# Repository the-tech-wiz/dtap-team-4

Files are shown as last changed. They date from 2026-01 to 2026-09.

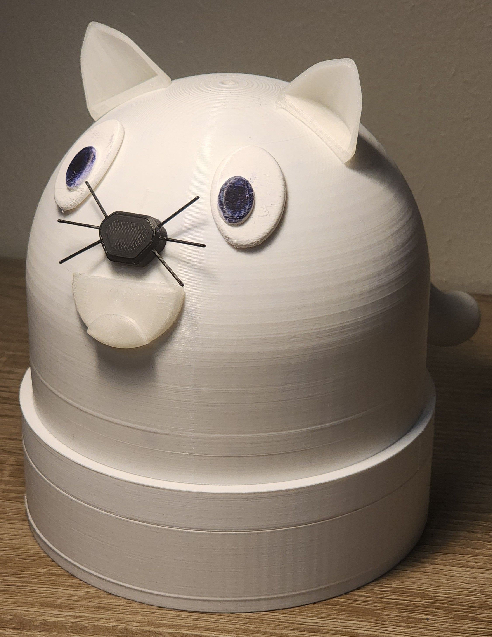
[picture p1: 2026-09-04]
image.jpg

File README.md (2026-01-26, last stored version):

# DTAP Team 4

## Getting started

To make it easy for you to get started with GitLab, here's a list of recommended next steps.

Already a pro? Just edit this README.md and make it your own. Want to make it easy? [Use the template at the bottom](#editing-this-readme)!

## Add your files

- [ ] [Create](https://docs.gitlab.com/ee/user/project/repository/web_editor.html#create-a-file) or [upload](https://docs.gitlab.com/ee/user/project/repository/web_editor.html#upload-a-file) files
- [ ] [Add files using the command line](https://docs.gitlab.com/topics/git/add_files/#add-files-to-a-git-repository) or push an existing Git repository with the following command:

```
cd existing_repo
git remote add origin https://version.aalto.fi/gitlab/lel4/dtap-team-4.git
git branch -M main
git push -uf origin main
```

## Integrate with your tools

- [ ] [Set up project integrations](https://version.aalto.fi/gitlab/lel4/dtap-team-4/-/settings/integrations)

## Collaborate with your team

- [ ] [Invite team members and collaborators](https://docs.gitlab.com/ee/user/project/members/)
- [ ] [Create a new merge request](https://docs.gitlab.com/ee/user/project/merge_requests/creating_merge_requests.html)
- [ ] [Automatically close issues from merge requests](https://docs.gitlab.com/ee/user/project/issues/managing_issues.html#closing-issues-automatically)
- [ ] [Enable merge request approvals](https://docs.gitlab.com/ee/user/project/merge_requests/approvals/)
- [ ] [Set auto-merge](https://docs.gitlab.com/user/project/merge_requests/auto_merge/)

## Test and Deploy

Use the built-in continuous integration in GitLab.

- [ ] [Get started with GitLab CI/CD](https://docs.gitlab.com/ee/ci/quick_start/)
- [ ] [Analyze your code for known vulnerabilities with Static Application Security Testing (SAST)](https://docs.gitlab.com/ee/user/application_security/sast/)
- [ ] [Deploy to Kubernetes, Amazon EC2, or Amazon ECS using Auto Deploy](https://docs.gitlab.com/ee/topics/autodevops/requirements.html)
- [ ] [Use pull-based deployments for improved Kubernetes management](https://docs.gitlab.com/ee/user/clusters/agent/)
- [ ] [Set up protected environments](https://docs.gitlab.com/ee/ci/environments/protected_environments.html)

***

# Editing this README

When you're ready to make this README your own, just edit this file and use the handy template below (or feel free to structure it however you want - this is just a starting point!). Thanks to [makeareadme.com](https://www.makeareadme.com/) for this template.

## Suggestions for a good README

Every project is different, so consider which of these sections apply to yours. The sections used in the template are suggestions for most open source projects. Also keep in mind that while a README can be too long and detailed, too long is better than too short. If you think your README is too long, consider utilizing another form of documentation rather than cutting out information.

## Name
Choose a self-explaining name for your project.

## Description
Let people know what your project can do specifically. Provide context and add a link to any reference visitors might be unfamiliar with. A list of Features or a Background subsection can also be added here. If there are alternatives to your project, this is a good place to list differentiating factors.

## Badges
On some READMEs, you may see small images that convey metadata, such as whether or not all the tests are passing for the project. You can use Shields to add some to your README. Many services also have instructions for adding a badge.

## Visuals
Depending on what you are making, it can be a good idea to include screenshots or even a video (you'll frequently see GIFs rather than actual videos). Tools like ttygif can help, but check out Asciinema for a more sophisticated method.

## Installation
Within a particular ecosystem, there may be a common way of installing things, such as using Yarn, NuGet, or Homebrew. However, consider the possibility that whoever is reading your README is a novice and would like more guidance. Listing specific steps helps remove ambiguity and gets people to using your project as quickly as possible. If it only runs in a specific context like a particular programming language version or operating system or has dependencies that have to be installed manually, also add a Requirements subsection.

## Usage
Use examples liberally, and show the expected output if you can. It's helpful to have inline the smallest example of usage that you can demonstrate, while providing links to more sophisticated examples if they are too long to reasonably include in the README.

## Support
Tell people where they can go to for help. It can be any combination of an issue tracker, a chat room, an email address, etc.

## Roadmap
If you have ideas for releases in the future, it is a good idea to list them in the README.

## Contributing
State if you are open to contributions and what your requirements are for accepting them.

For people who want to make changes to your project, it's helpful to have some documentation on how to get started. Perhaps there is a script that they should run or some environment variables that they need to set. Make these steps explicit. These instructions could also be useful to your future self.

You can also document commands to lint the code or run tests. These steps help to ensure high code quality and reduce the likelihood that the changes inadvertently break something. Having instructions for running tests is especially helpful if it requires external setup, such as starting a Selenium server for testing in a browser.

## Authors and acknowledgment
Show your appreciation to those who have contributed to the project.

## License
For open source projects, say how it is licensed.

## Project status
If you have run out of energy or time for your project, put a note at the top of the README saying that development has slowed down or stopped completely. Someone may choose to fork your project or volunteer to step in as a maintainer or owner, allowing your project to keep going. You can also make an explicit request for maintainers.

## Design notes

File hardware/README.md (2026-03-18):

# Hardware

Hardware files such as CAD or PCB for DTAP Team 4 project.

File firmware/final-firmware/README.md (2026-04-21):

# Final firmware

Final all-in-one firmware Arduino project for firmware.

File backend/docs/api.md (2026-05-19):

# API Reference

Base URL: `http://<VM_EXTERNAL_IP>:3000`  
Local development: `http://localhost:3000`

> **Note:** The VM does not currently have a static IP. Retrieve the current external IP with:
> ```bash
> gcloud compute instances describe mqtt-api-server --zone=europe-north1-a \
>   --format="get(networkInterfaces[0].accessConfigs[0].natIP)"
> ```

---

## Health

### GET /health

Returns the status of the API server and its MQTT broker connection.

**Request**
```
GET /health
```

**Response `200 OK`**
```json
{
  "status": "ok",
  "timestamp": "2025-01-15T10:30:00.000Z",
  "uptime": "42s",
  "services": {
    "api": "running",
    "mqtt": "connected"
  }
}
```

| Field | Type | Description |
|---|---|---|
| `status` | string | Always `"ok"` if the server is reachable. |
| `timestamp` | string | ISO 8601 timestamp of the response. |
| `uptime` | string | Time since the server process started. |
| `services.api` | string | Always `"running"`. |
| `services.mqtt` | string | MQTT broker connection state: `"connected"` or `"disconnected"`. |

---

### GET /health/ping

Simple liveness check.

**Request**
```
GET /health/ping
```

**Response `200 OK`**
```json
{
  "pong": true,
  "timestamp": "2025-01-15T10:30:00.000Z"
}
```

---

## Device

### GET /device

Returns the cached state for all known devices. State is populated from incoming MQTT `status` and `telemetry` messages and held in memory.

**Request**
```
GET /device
```

**Response `200 OK`**
```json
{
  "devices": {
    "device-1": {
      "status": {
        "online": true,
        "playing": true,
        "trackId": 3,
        "volume": 50,
        "receivedAt": "2025-01-15T10:30:00.000Z"
      },
      "telemetry": {
        "receivedAt": "2025-01-15T10:29:55.000Z"
      }
    }
  }
}
```

> **Note:** Response shape depends on what MQTT messages have been received since the server started. No database is used — state resets on server restart. Each sub-object (`status`, `telemetry`) is the raw JSON payload from the device with a `receivedAt` field appended.

---

### GET /device/:id/state

Returns the cached state for a single device.

**Request**
```
GET /device/:id/state
```

**Path Parameters**

| Parameter | Type | Description |
|---|---|---|
| `id` | string | The device ID (e.g. `device-1`) |

**Response `200 OK`**
```json
{
  "deviceId": "device-1",
  "state": {
    "status": {
      "online": true,
      "playing": true,
      "trackId": 3,
      "volume": 50,
      "receivedAt": "2025-01-15T10:30:00.000Z"
    },
    "telemetry": {
      "receivedAt": "2025-01-15T10:29:55.000Z"
    }
  }
}
```

**Response `404 Not Found`**
```json
{
  "error": "Device not found or has not reported yet",
  "deviceId": "device-1"
}
```

Returned if no MQTT messages have been received for the given device ID since the server started.

---

### POST /device/:id/command

Publishes a command to a device via the MQTT broker on the topic `device/{id}/command`.

**Request**
```
POST /device/:id/command
Content-Type: application/json
```

**Path Parameters**

| Parameter | Type | Description |
|---|---|---|
| `id` | string | The target device ID (e.g. `device-1`) |

**Request Body**

```json
{
  "command": "playTrack",
  "payload": {
    "trackId": 3
  }
}
```

| Field | Type | Required | Description |
|---|---|---|---|
| `command` | string | Yes | The command name to send to the device |
| `payload` | object | No | Additional parameters for the command. Defaults to `{}` if omitted. |

**Supported commands**

| `command` | `payload` | Effect |
|---|---|---|
| `playTrack` | `{ "trackId": <number> }` | Play audio track by ID from SD card |
| `stopPlayback` | — | Stop current playback |
| `setVolume` | `{ "volume": <0–100> }` | Set output volume |

**Response `200 OK`**
```json
{
  "success": true,
  "deviceId": "device-1",
  "command": "playTrack",
  "publishedTo": "device/device-1/command"
}
```

**Response `400 Bad Request`**
```json
{
  "error": "Missing required field: command"
}
```

**Response `500 Internal Server Error`**
```json
{
  "error": "Failed to send command to device"
}
```

Returned if the MQTT publish fails (e.g. broker is unreachable).

---

## MQTT Topic Reference

The API interacts with the following MQTT topics internally. These are not HTTP endpoints but are documented here for cross-team reference.

| Topic | Direction | Description |
|---|---|---|
| `device/{id}/status` | Device → API | Device playback state (online, playing, trackId, volume) |
| `device/{id}/telemetry` | Device → API | Sensor readings and diagnostics |
| `device/{id}/command` | API → Device | Commands published by the POST endpoint |

The API subscribes to `device/+/status` (QoS 1) and `device/+/telemetry` (QoS 0) on startup.

Commands are published as JSON:
```json
{
  "command": "playTrack",
  "payload": { "trackId": 3 },
  "sentAt": "2025-01-15T10:30:00.000Z"
}
```

---

## Testing Locally

With the dev server running (`npm run dev`), you can test endpoints with curl:

```bash
# Health checks
curl http://localhost:3000/health
curl http://localhost:3000/health/ping

# Device state
curl http://localhost:3000/device
curl http://localhost:3000/device/device-1/state

# Send commands
curl -X POST http://localhost:3000/device/device-1/command \
  -H "Content-Type: application/json" \
  -d '{"command": "playTrack", "payload": {"trackId": 3}}'

curl -X POST http://localhost:3000/device/device-1/command \
  -H "Content-Type: application/json" \
  -d '{"command": "stopPlayback"}'

curl -X POST http://localhost:3000/device/device-1/command \
  -H "Content-Type: application/json" \
  -d '{"command": "setVolume", "payload": {"volume": 75}}'
```

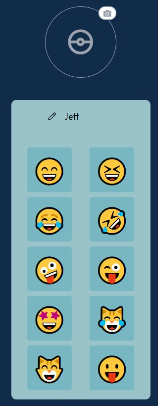
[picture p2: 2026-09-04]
ui.png

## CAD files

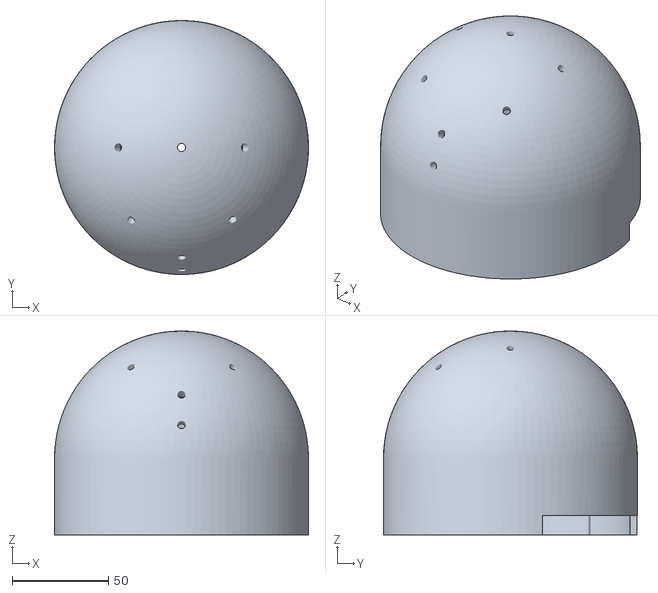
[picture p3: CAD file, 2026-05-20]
hardware/cad/stl/Outer Shell Full.stl
132.0 x 132.0 x 106.0

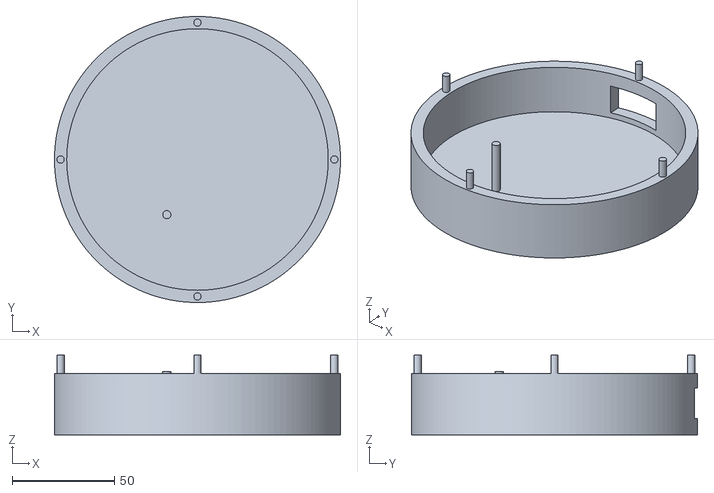
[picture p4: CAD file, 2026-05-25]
hardware/cad/stl/battery pack.stl
140.0 x 140.0 x 39.0

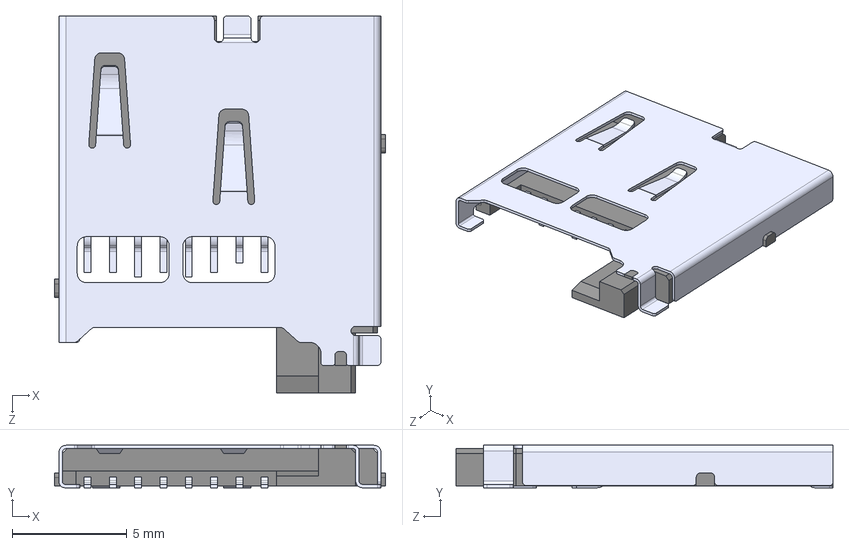
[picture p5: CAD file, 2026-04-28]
hardware/pcb-design/parts/GTFP08441BEU/GTFP08441BEU.step
14.4 x 1.85 x 16.4 mm

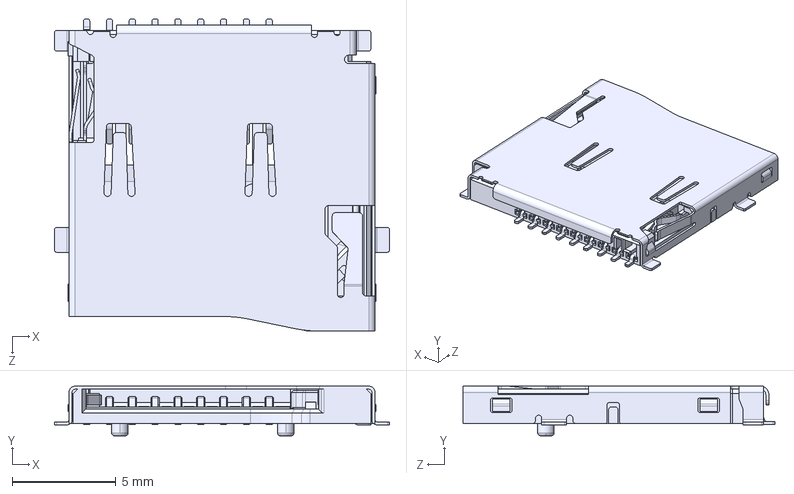
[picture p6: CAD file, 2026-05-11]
hardware/pcb-design/parts/MSD-4-A/MSD-4-A.step
16.1 x 2.40 x 15.0 mm

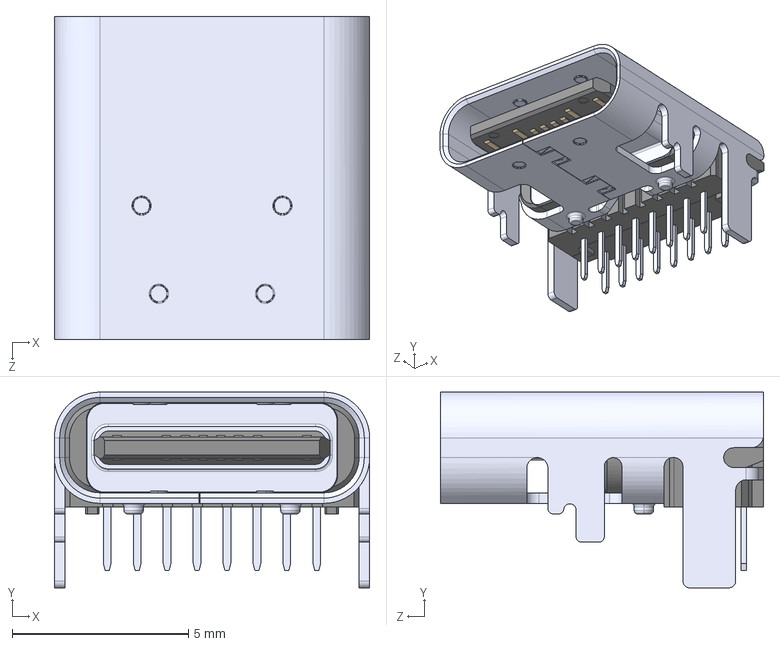
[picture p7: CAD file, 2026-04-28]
hardware/pcb-design/parts/USB4085-GF-A_REVA4/USB4085-GF-A_REVA4.step
8.95 x 5.56 x 9.17 mm

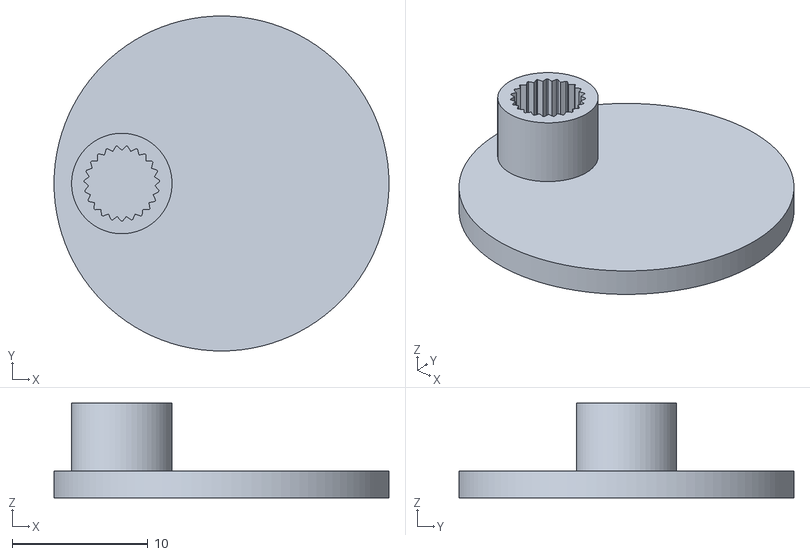
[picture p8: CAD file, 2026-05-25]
hardware/cad/stl/unbalnced circle horn 5.5 mm.stl
24.7 x 24.7 x 7.00

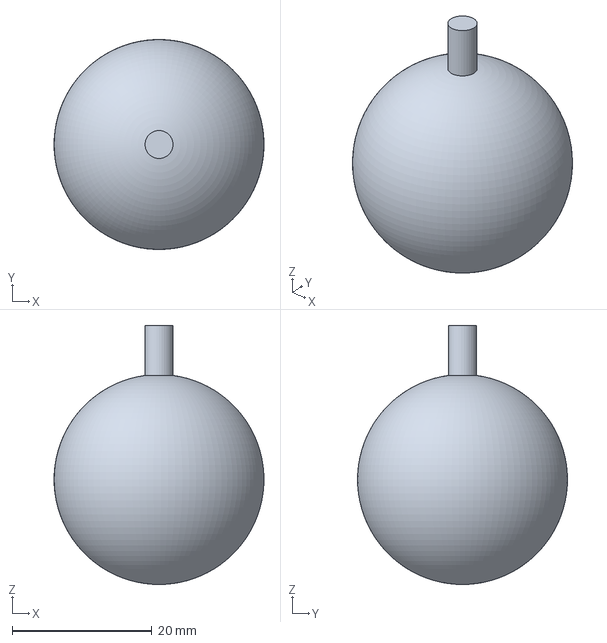
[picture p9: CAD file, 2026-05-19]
hardware/cad/sliced/Tail Rabbit.3mf
30.0 x 30.0 x 37.0 mm

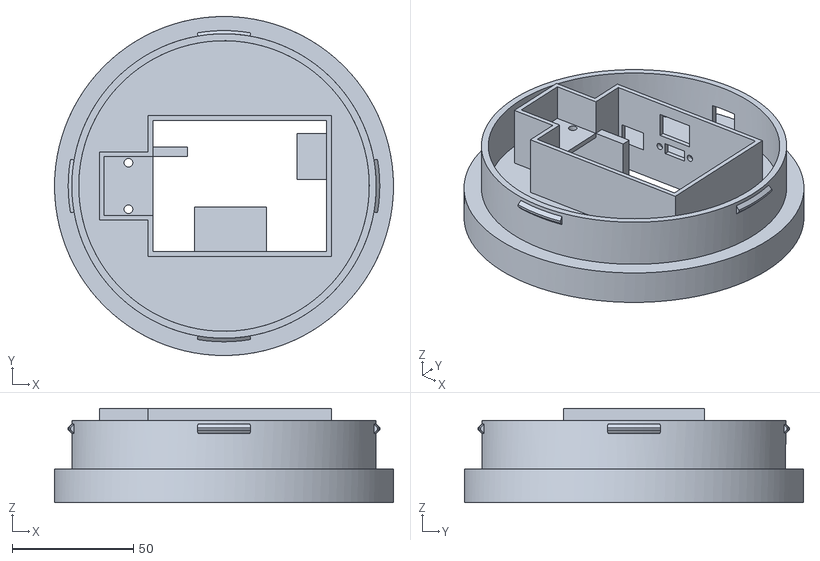
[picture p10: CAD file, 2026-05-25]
hardware/cad/stl/Base w Comp Box V2.stl
140.0 x 140.0 x 39.0

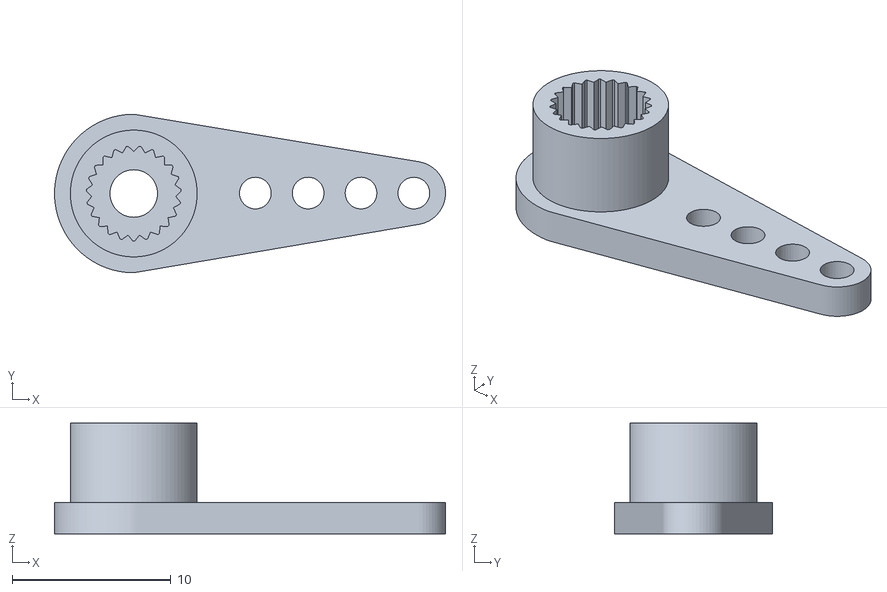
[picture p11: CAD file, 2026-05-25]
hardware/cad/stl/servo horn inner diameter 5mm.stl
24.7 x 9.99 x 7.00

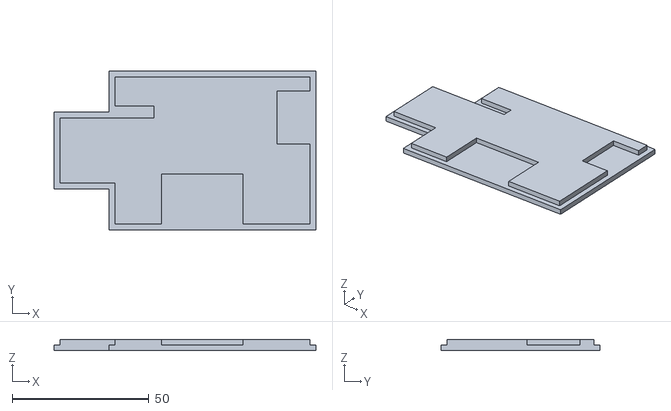
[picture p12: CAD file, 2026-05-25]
hardware/cad/stl/Component Box Bottom Lid V2.stl
95.8 x 58.2 x 4.00

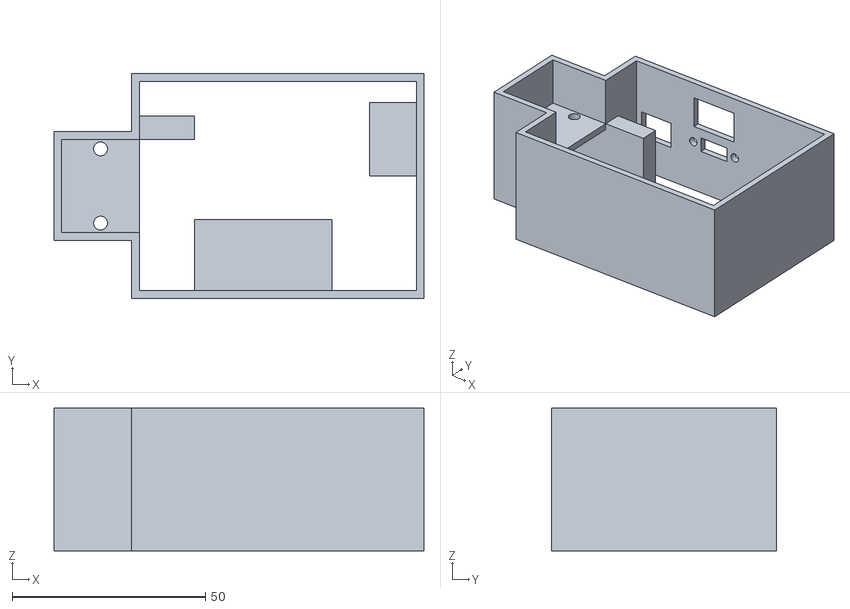
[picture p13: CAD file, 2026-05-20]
hardware/cad/stl/Component Box.stl
95.8 x 58.2 x 37.0

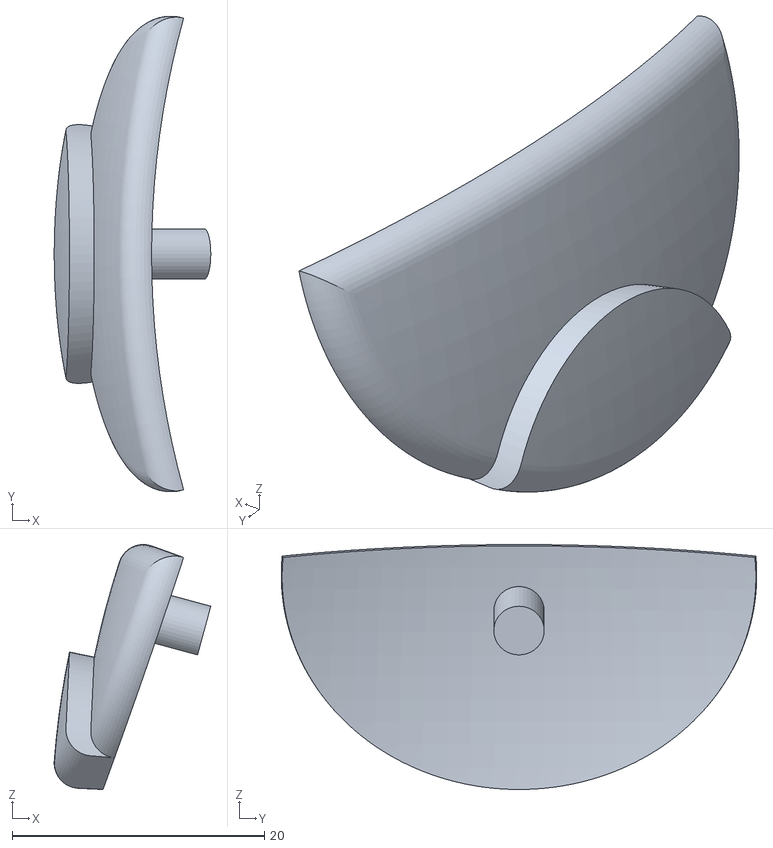
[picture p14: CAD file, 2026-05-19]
hardware/cad/stl/Mouth Happy.stl
12.4 x 37.7 x 19.4

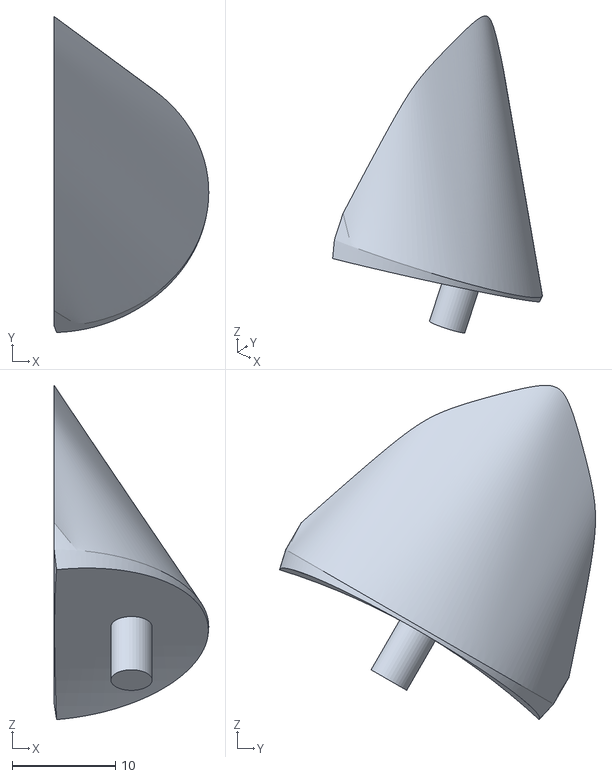
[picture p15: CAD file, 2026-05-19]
hardware/cad/stl/Ear Cat.stl
15.0 x 30.7 x 32.4

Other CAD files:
hardware/cad/sliced/Bottom Lid V2.gcode.3mf
hardware/cad/sliced/Base V2.gcode.3mf
hardware/cad/stl/Component Box Top Lid.stl
hardware/cad/stl/unbalanced circular servo horn 5.5mm.stl
hardware/cad/stl/Tail Rabbit.stl
hardware/cad/fusion/Component Box.f3d
hardware/cad/fusion/outer shell but 3mm thickness for wall (new component box).f3d
hardware/cad/fusion/outer shell but 3mm thickness for wall.f3d
hardware/cad/fusion/unbalanced circular servo horn 5.5mm.f3d
hardware/cad/fusion/upper outer shell and body joints.f3d
hardware/cad/stl/Ear Rabbit.stl
hardware/cad/stl/Eye L.stl
hardware/cad/stl/Eye R.stl
hardware/cad/stl/Nose Cat (Black).stl
hardware/cad/stl/Nose Rabbit (Pink).stl
hardware/cad/stl/Tail Cat.stl

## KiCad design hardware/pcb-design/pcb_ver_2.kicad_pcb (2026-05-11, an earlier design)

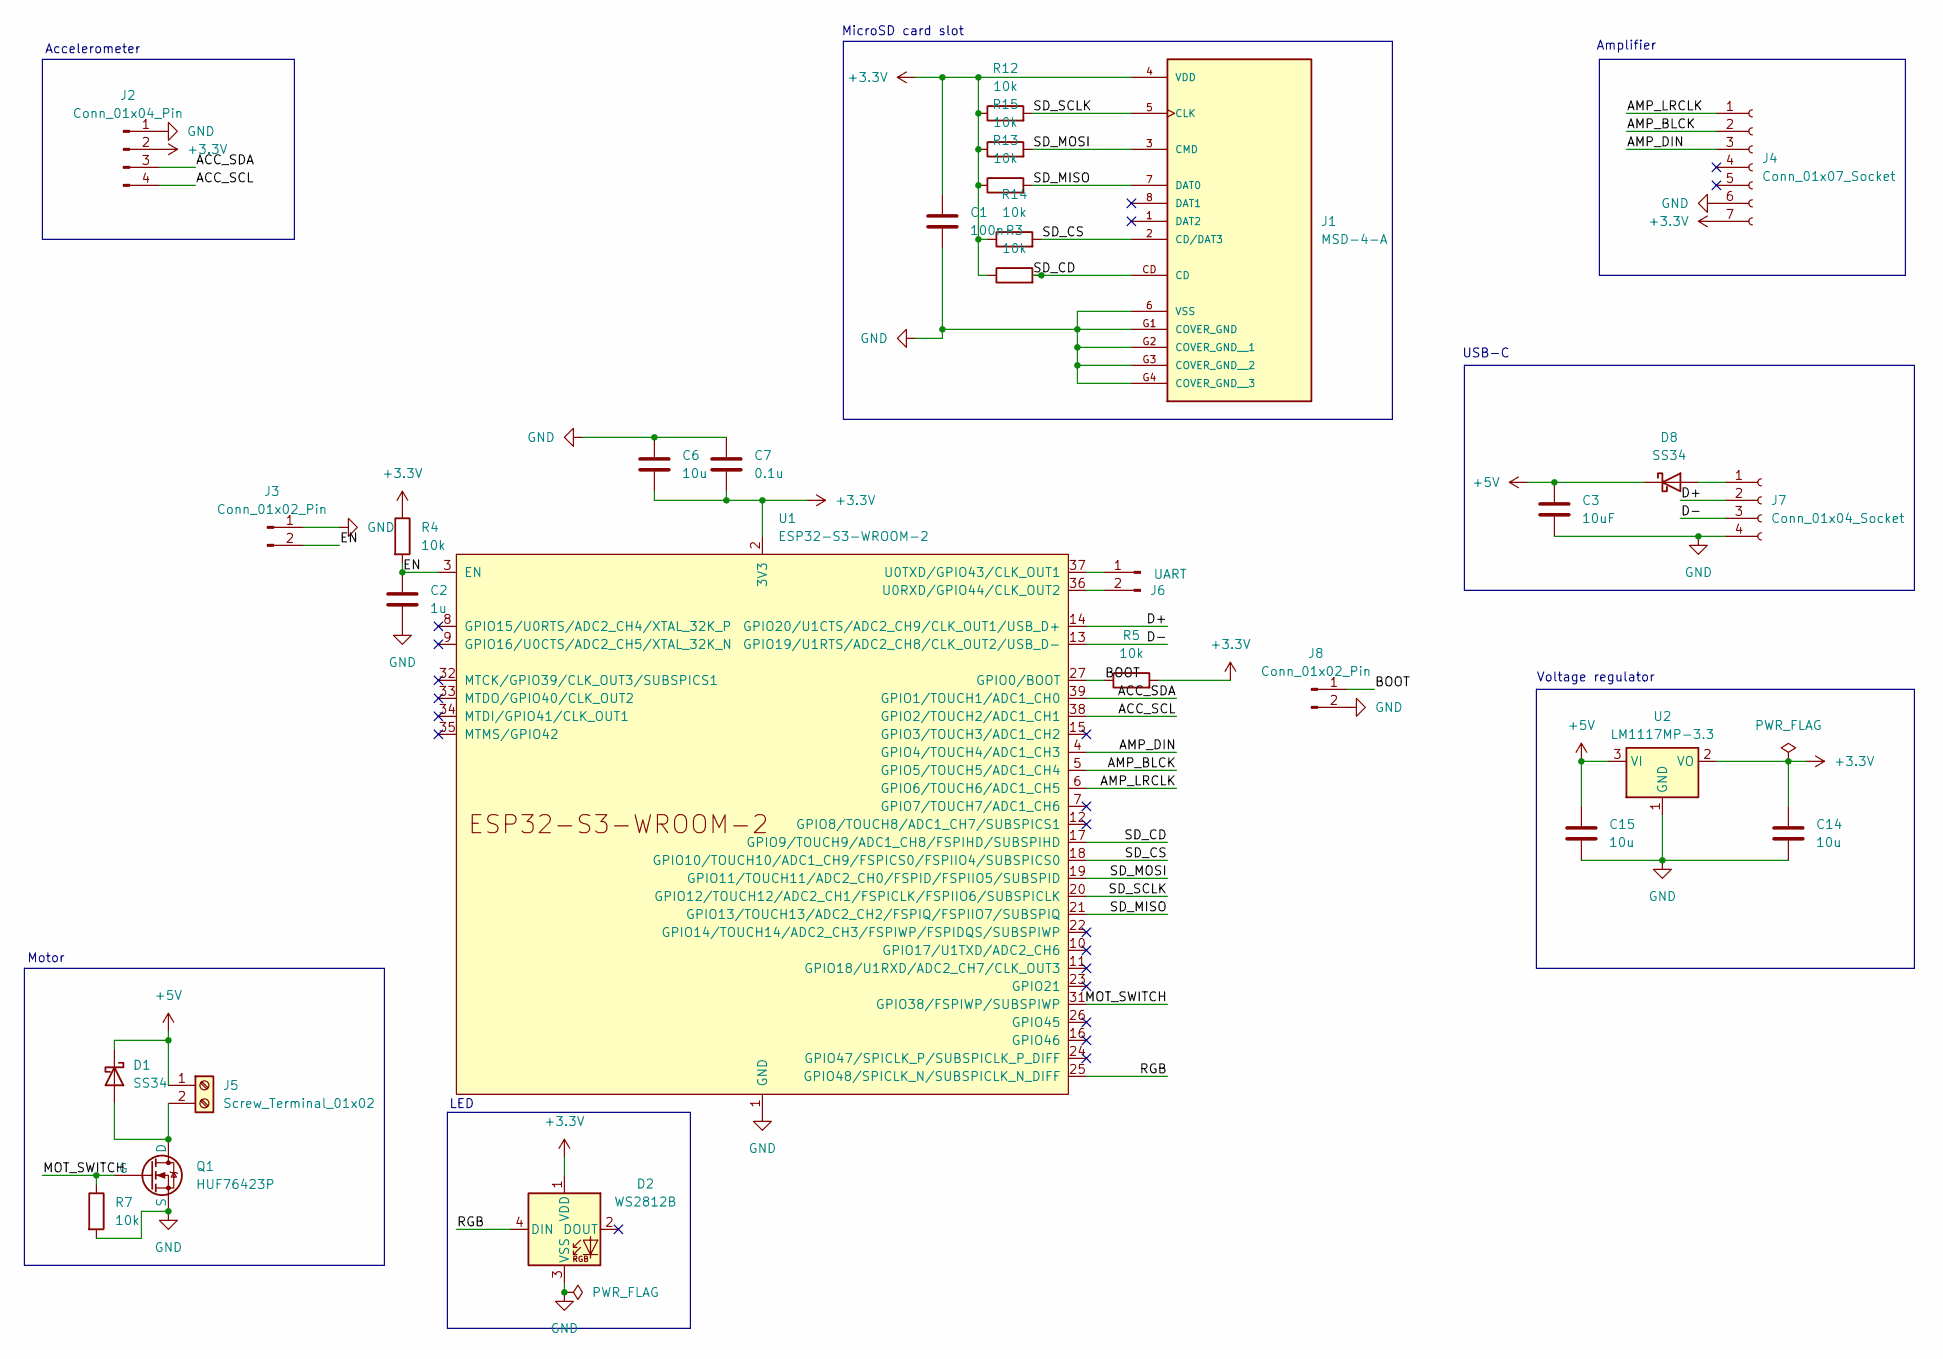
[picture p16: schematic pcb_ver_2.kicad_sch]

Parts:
C1: 100n; C_0603_1608Metric_Pad1.08x0.95mm_HandSolder
C2: 1u; C_0603_1608Metric_Pad1.08x0.95mm_HandSolder
C3: 10uF; C_0805_2012Metric_Pad1.18x1.45mm_HandSolder
C6, C14, C15: 10u; C_0805_2012Metric_Pad1.18x1.45mm_HandSolder
C7: 0.1u; C_0603_1608Metric_Pad1.08x0.95mm_HandSolder
D1, D8: SS34; D_SMB-SMC_Universal_Handsoldering
D2: WS2812B; LED_WS2812B_PLCC4_5.0x5.0mm_P3.2mm
J1: MSD-4-A; CUI_MSD-4-A; PARTREV 1.0
J2: Conn_01x04_Pin; NS-Tech_Grove_1x04_P2mm_Vertical
J3, J8: Conn_01x02_Pin; PinSocket_2x01_P2.54mm_Vertical
J4: Conn_01x07_Socket; PinHeader_1x07_P2.54mm_Vertical
J5: Screw_Terminal_01x02; TerminalBlock_RND_205-00012_1x02_P5.00mm_Horizontal
J6: UART; PinHeader_1x02_P2.54mm_Horizontal
J7: Conn_01x04_Socket; NS-Tech_Grove_1x04_P2mm_Vertical
Q1: HUF76423P; TO-220-3_Vertical
R3, R4, R5, R7, R12, R13, R14, R15: 10k; R_0603_1608Metric_Pad0.98x0.95mm_HandSolder
U1: ESP32-S3-WROOM-2
U2: LM1117MP-3.3; SOT-223-3_TabPin2

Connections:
+3.3V: C1.1, C6.2, C7.2, C14.1, D2.1 (VDD), J1.4 (VDD), J2.2, J4.7, R3.1, R4.1, R5.2, R12.1, R13.1, R14.1, R15.1, U1.2 (3V3), U2.2 (VO)
+5V: C3.1, C15.1, D1.1 (K), D8.1 (K), J5.1, U2.3 (VI)
/ACC_SCL: J2.4, U1.38 (GPIO2/TOUCH2/ADC1_CH1)
/ACC_SDA: J2.3, U1.39 (GPIO1/TOUCH1/ADC1_CH0)
/AMP_BLCK: J4.2, U1.5 (GPIO5/TOUCH5/ADC1_CH4)
/AMP_DIN: J4.3, U1.4 (GPIO4/TOUCH4/ADC1_CH3)
/AMP_LRCLK: J4.1, U1.6 (GPIO6/TOUCH6/ADC1_CH5)
/BOOT: J8.1, R5.1, U1.27 (GPIO0/BOOT)
/D+: J7.2, U1.14 (GPIO20/U1CTS/ADC2_CH9/CLK_OUT1/USB_D+)
/D-: J7.3, U1.13 (GPIO19/U1RTS/ADC2_CH8/CLK_OUT2/USB_D-)
/EN: C2.1, J3.2, R4.2, U1.3 (EN)
/MOT_SWITCH: Q1.2 (G), R7.1, U1.31 (GPIO38/FSPIWP/SUBSPIWP)
/RGB: D2.4 (DIN), U1.25 (GPIO48/SPICLK_N/SUBSPICLK_N_DIFF)
/SD_CD: J1.CD, R3.2, U1.17 (GPIO9/TOUCH9/ADC1_CH8/FSPIHD/SUBSPIHD)
/SD_CS: J1.2 (CD/DAT3), R14.2, U1.18 (GPIO10/TOUCH10/ADC1_CH9/FSPICS0/FSPIIO4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)
/SD_MISO: J1.7 (DAT0), R13.2, U1.21 (GPIO13/TOUCH13/ADC2_CH2/FSPIQ/FSPIIO7/S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)
/SD_MOSI: J1.3 (CMD), R15.2, U1.19 (GPIO11/TOUCH11/ADC2_CH0/FSPID/FSPIIO5/S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)
/SD_SCLK: J1.5 (CLK), R12.2, U1.20 (GPIO12/TOUCH12/ADC2_CH1/FSPICLK/FSPIIO6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)
GND: C1.2, C2.2, C3.2, C6.1, C7.1, C14.2, C15.2, D2.3 (VSS), J1.6 (VSS), J1.G1 (COVER_GND), J1.G2 (COVER_GND__1), J1.G3 (COVER_GND__2), J1.G4 (COVER_GND__3), J2.1, J3.1, J4.6, J7.4, J8.2, Q1.3 (S), R7.2, U1.1 (GND), U1.40 (GND), U1.41 (GND), U2.1 (GND)
unnamed: D1.2 (A), J5.2, Q1.1 (D)
unnamed: D8.2 (A), J7.1
unnamed: J6.1, U1.37 (U0TXD/GPIO43/CLK_OUT1)
unnamed: J6.2, U1.36 (U0RXD/GPIO44/CLK_OUT2)

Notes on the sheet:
Voltage regulator
LED
MicroSD card slot
Accelerometer
Motor
USB-C
Amplifier

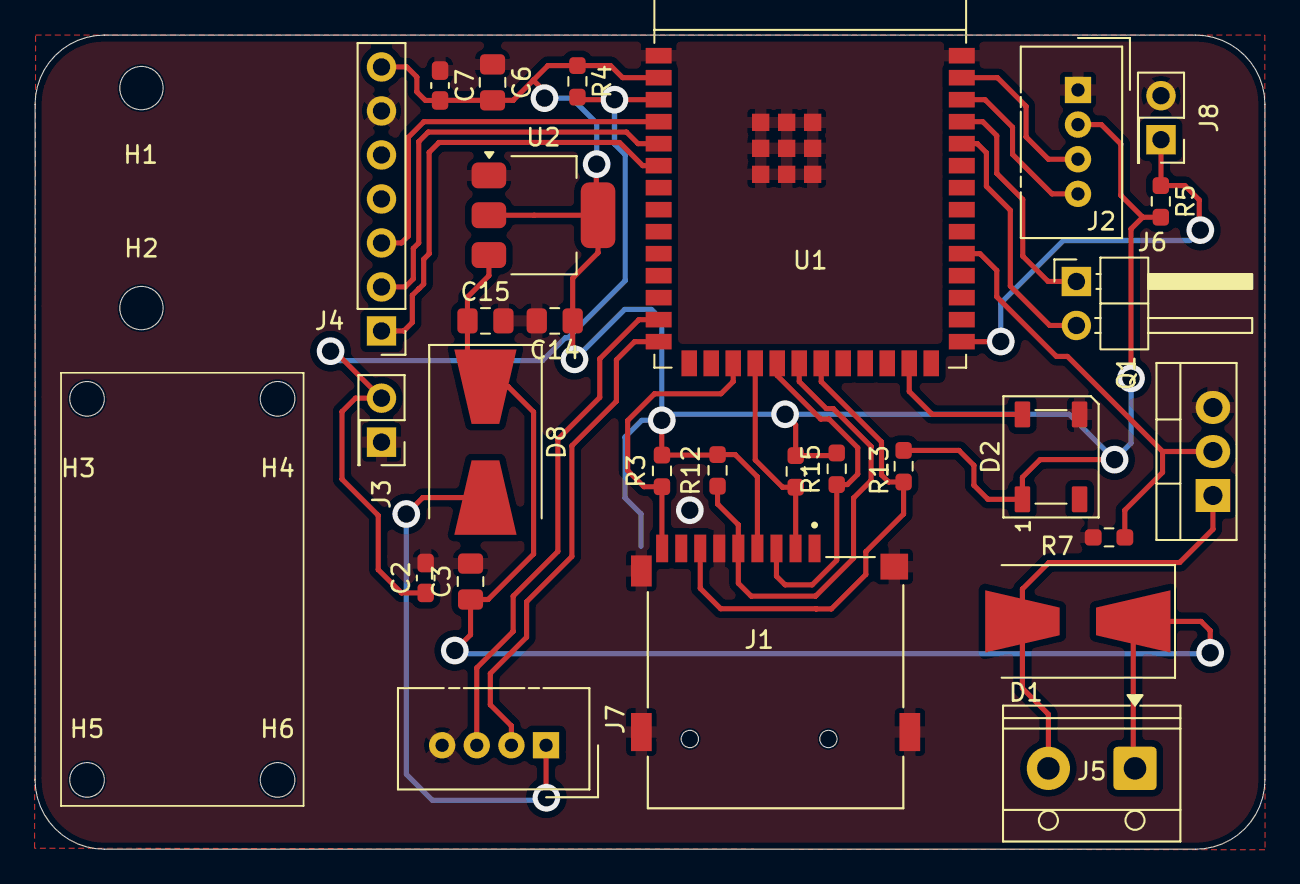
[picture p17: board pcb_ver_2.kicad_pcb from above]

Board: 2 copper layers, 71.0 x 47.0 mm, 35 parts (1 on the bottom side), 23 nets.

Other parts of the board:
H1, H2: MountingHole_2.5mm
H3, H4, H5, H6: MountingHole_2mm

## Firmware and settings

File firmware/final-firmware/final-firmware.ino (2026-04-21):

/*
 * HARDWARE SETUP:
 *
 * TODO: Write code to test MicroSD card adapter and amplifier
 * TODO: Network interface code
 *
 * Debug Levels (set PROTOFLOW_DEBUG_LEVEL before including library):
 * 0 = No debug output (production)
 * 3 = Errors + Warnings + Info (recommended for development)
 * 5 = Verbose (detailed debugging)
 */

#define PROTOFLOW_DEBUG_LEVEL 3
#include <AaltoProtoFlow.h>

// ============================================================================
// YOUR PROJECT NAME - This appears in the PWA device list
// ============================================================================
#define DEVICE_NAME "Laugh-With-Me Buddy"  // <-- CHANGE THIS!

// ============================================================================
// Setup
// ============================================================================
void setup() {
    // --- Device configuration ---
    ProtoFlow.configureDevice(DEVICE_NAME, "ESP32");

    Serial.begin(115200);
    delay(300);
    outputSetup();
    sensorSetup();   
}

// ============================================================================
// Loop
// ============================================================================
void loop() {
    // Each .loop() call reads the sensor and sends data if needed
    sense();
    delay(150);
}

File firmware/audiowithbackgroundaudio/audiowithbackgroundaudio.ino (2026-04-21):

// Testing BackgroundAudio library with ESP32, SD card, PCM5102 (DAC) and PAM8302A (amp)

// Play MP3 file from SD card

#include <BackgroundAudioMP3.h>
#include <ESP32I2SAudio.h>
#include <SD.h>

// I/O for DAC
#define DAC_LRCK 32
#define DAC_BCK  25
#define DAC_DIN  33

// file name to play as default/fallback audio
#define DEFAULT_AUDIO "/default_laugh.mp3"

ESP32I2SAudio audio(DAC_BCK, DAC_LRCK, DAC_DIN);
File f;
uint8_t filebuff[512];
BackgroundAudioMP3 player(audio);

// handling failure
// void fail() {
//   while (1) {
//     if (Serial.available()) Serial.println("Restarting");
//     delay(1000);
//     ESP.restart();
//   }
// }

void setup() {
  Serial.begin(115200);
  delay(300);
  Serial.println("Start program");

  // initialize SD card
  if (!SD.begin()) {
    Serial.println("Fail to read SD card");
    // fail();
  } else Serial.println("Opened SD card");

  f = SD.open(DEFAULT_AUDIO);
  if (!f) {
    Serial.printf("Unable to open %s", DEFAULT_AUDIO);
    // fail();
  } else Serial.println("Opened file");

  player.begin();
  player.setGain(0.01);
  Serial.println("Start playing");
}

void loop() {
  int count = 0;
  while (f && player.availableForWrite() > 512) {
    int len = f.read(filebuff, 512);
    player.write(filebuff, len);
    if(len != 512) {
      f.close();
    }
  }
}

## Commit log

2026-04-01 firmware: code for vibrator, piezo sensor
    [initial-test.ino]
2026-04-01 firmware: copied code to final-firmware arduino project
2026-04-01 renamed device
2026-04-03 firmware/final-firmware: fixed incomplete rename
    [final-firmware.ino]
2026-04-21 ignored arduino config
2026-04-21 moved gitignore outside to ignore arduino
2026-04-21 hacky fix to reload laugh
    [output.ino]
2026-04-27 Added a simulator/device.js so we can test the 'device' locally.
2026-04-27 changed device name from 'pelican-1' to 'device-1'
2026-04-28 hardware: pcb version with esp32 devkit
    [ABLF2040A.step, GTFP08441BEU.step, USB4085-GF-A_REVA4.step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]
2026-04-30 Connection between frontend code buttons and backend complete! Funcitons currently working: playTrack, stopTrack, setVolume
2026-04-30 removing volume print
2026-05-05 hardware: complete schematic and pcb
    [GTFP08441BEU.step, USB4085-GF-A_REVA4.step, pcb_ver_1.kicad_pcb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]
2026-05-05 hardware: clean up folder
    [ABLF2040A.step, GTFP08441BEU.step, USB4085-GF-A_REVA4.step]
2026-05-06 Changeable device name
2026-05-06 Changable device picture
2026-05-06 hardware: change to USB board
    [pcb_ver_2.kicad_pcb, pcb_ver_2.kicad_sch]
2026-05-11 hardware: remove vias and change sizes
    [MSD-4-A.step, pcb_ver_2.kicad_pcb, pcb_ver_2.kicad_sch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]
2026-05-14 media bar dissapears when no track is set
2026-05-18 frontend: bugfix: pressing the save button while editing puts the user back to editing
2026-05-19 frontend: changed image selector button
2026-05-19 added repo for fushion, stl, and sliced files
    [outer shell but 3mm thickness for wall.f3d, unbalanced circular servo horn 5.5mm.f3d, upper outer shell and body joints.f3d]
2026-05-19 added body joints excluding ears as stl forms
    [Eye L.stl, Eye R.stl, Mouth Happy.stl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]
2026-05-19 add more body joints w ears as stl, reduce joint length
    [Ear Cat.stl, Ear Rabbit.stl, Eye L.stl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]
2026-05-19 add rabbit tail and motor as stl
    [Mouth Happy.stl, Tail Rabbit.stl, unbalanced circular servo horn 5.5mm.stl]
2026-05-19 Updated the backend api.md to be relevent to current state
2026-05-19 hardware: erm actually renamed
    [Ear Cat.stl, Ear Rabbit.stl, Eye L.stl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]
2026-05-20 add new component box, integrate it with base, as stl & fusion
    [Base with Comp and Vibr Boxes.stl, Component Box Bottom Lid.stl, Component Box Top Lid.stl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]
2026-05-22 frontend: changed out the accordion for emoji buttons
2026-05-22 frontend: changed button color to make it look softer
2026-05-22 frontend: made the emoji buttons larger
2026-05-22 frontend: centered the device name
2026-05-23 frontend: rename device
2026-05-25 fist attempt to add frontend status of device rendering
2026-05-25 update base with component box and its bottom lid
    [Base V2.gcode.3mf, Base w Comp Box V2.stl, Base with Comp and Vibr Boxes.stl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]
